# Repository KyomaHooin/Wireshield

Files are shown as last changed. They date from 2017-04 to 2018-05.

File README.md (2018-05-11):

DESCRIPTION

Server Rack Waste Heat Monitoring.

FILE
<pre>
                 avr/ - Atmega code.
               photo/ - Photo documentation.
               kicad/ - KiCAD schematic and PCB.
            openscad/ - OpenSCAD case model.
           raspberry/ - RPi code.
wireshield_schema.pdf - Shield schematic.
</pre>
SOURCE

https://github.com/KyomaHooin/Wireshield

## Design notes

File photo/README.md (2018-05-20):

DESCRIPTION

Photo documentation for Wireshield.

FILE
<pre>
IMG_20170406_092021.jpg - LED blinking.
IMG_20170406_093931.jpg - Activity LED added.
IMG_20170407_105513.jpg - Raspberry connection.
IMG_20170412_122922.jpg - Temp sensor added.
IMG_20170419_115917.jpg - TFT display test.
IMG_20170502_114444.jpg - Temp sensor connected via Cat 5e.
IMG_20170718_132216.jpg - PCB.
IMG_20170807_113755.jpg - Testing PCB.
IMG_20170830_094421.jpg - Test revision 2.0.
IMG_20170830_094432.jpg - TFT display test.
IMG_20180214_163721.jpg - 3D print case prototype.
IMG_20180219_162749.jpg - Front view of Wireshield (with wrong screwed screw)
IMG_20180219_162757.jpg - Side view of Wireshield (without button)
IMG_20180220_111011.jpg - Side view of Wireshield 
IMG_20180220_111004.jpg - Front view of Wireshield
IMG_20180412_110601.jpg - Final box connector side.
IMG_20180412_110608.jpg - Final box.
</pre>

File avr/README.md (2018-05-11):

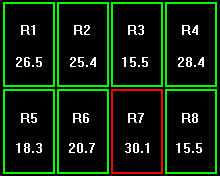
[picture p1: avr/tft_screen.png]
TFT


DESCRIPTION

OneWire AVR shield Atmega328 code.

FILE

<pre>
     rpishield.ino - Main  Program.
    tft_screen.png - Display screenshot.
       OneWire.zip - Dallas Onewire bus library by Paul Stoffregen (c) 2017.
      LowPower.zip - Low power library by Lim Phang Moh.
TFT_22_ILI9225.zip - ILI9225 TFT HW SPI driver by Johan Cronje Nkawu (c) 2017.
</pre>

SOURCE

https://github.com/KyomaHooin/Wireshield

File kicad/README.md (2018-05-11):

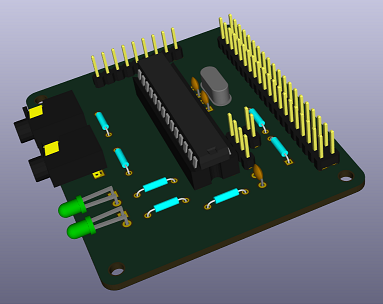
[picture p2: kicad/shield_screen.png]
Shield


DESCRIPTION

Raspberry RPi2 OneWire AVR shield PCB.

FILE
<pre>
                3d/ - 3D models by Walter Lain (c) 2015.
  footprint.pretty/ - Custom footprints.
rpishield.kicad_pcb - PCB layout.
      rpishield.pro - Project file.
      rpishield.lib - Project library.
      rpishield.sch - Custom schematic.
      rpishield.net - Trace list.
  shield_screen.png - Board screenshot.
</pre>
SOURCE

https://github.com/KyomaHooin/Wireshield

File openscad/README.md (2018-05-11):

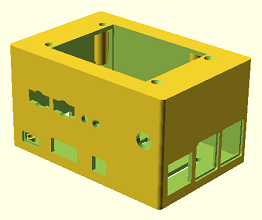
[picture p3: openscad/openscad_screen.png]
Openscad


DESCRIPTION

Raspberry RPi2 AVR shield & TFT display case.

FILE
<pre>
            schema/ - Dimension schematics.

rpishield_bottom.stl - Bottom STL file.
rpishield_spacer.stl - Spacer STL file.
   rpishield_top.stl - Top STL file.
      rpishield.scad - Complete code.
         shield.scad - Shield code.
            rpi.scad - RPi code.
            tft.scad - TFT display code.
             fc.scad - Helper functions.
 openscad_screen.png - 3D model screenshot.
</pre>
SOURCE

https://github.com/KyomaHooin/Wireshield

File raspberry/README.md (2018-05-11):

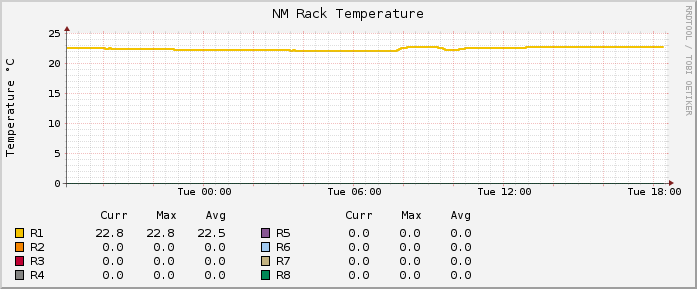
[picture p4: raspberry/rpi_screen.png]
RPI


DESCRIPTION

RPi2 AVR shield server configuration.

INSTALL
<pre>
apt-get install apache2 python-serial python-rrdtool watchdog

raspi-config > Interfacing Options > Serial > logging [no] > device [yes]

systemctl disable serial-getty@ttyAMA0.service

/etc/rc.local:

/root/avr/rpi-avr.py &
/root/avr/rstpwr.py &
/root/firewall &

/etc/network/interfaces:

auto eth0
iface eth0 inet static
	address 10.10.19.222
	netmask 255.255.0.0
	gateway 10.10.10.43
	dns-nameservers 10.10.9.26 10.10.9.27

/etc/watchdog.conf:

watchdog-device = /dev/watchdog
watchdog-timeout = 15

/etc/ntp.conf:

server tik.cesnet.cz
server tak.cesnet.cz

/etc/apache2/sites-enabled/000-default.conf:

ServerName xxx.xx.cz

DocumentRoot /var/www/rpishield

&lt;Directory /var/www/rpishield/plot&gt;
Options -Indexes -Multiviews
Order Allow,Deny
Allow from all
&lt;/Directory&gt;
</pre>
FILE
<pre>
     frontend/ - HTML frontend.

    rpi-avr.py - AVR data processing.
     rstpwr.py - Reset/halt detection.
   database.py - Create RRD database.
      firewall - Firewall script.
rpi_screen.png - Plot output.
</pre>
SOURCE

https://github.com/KyomaHooin/Wireshield

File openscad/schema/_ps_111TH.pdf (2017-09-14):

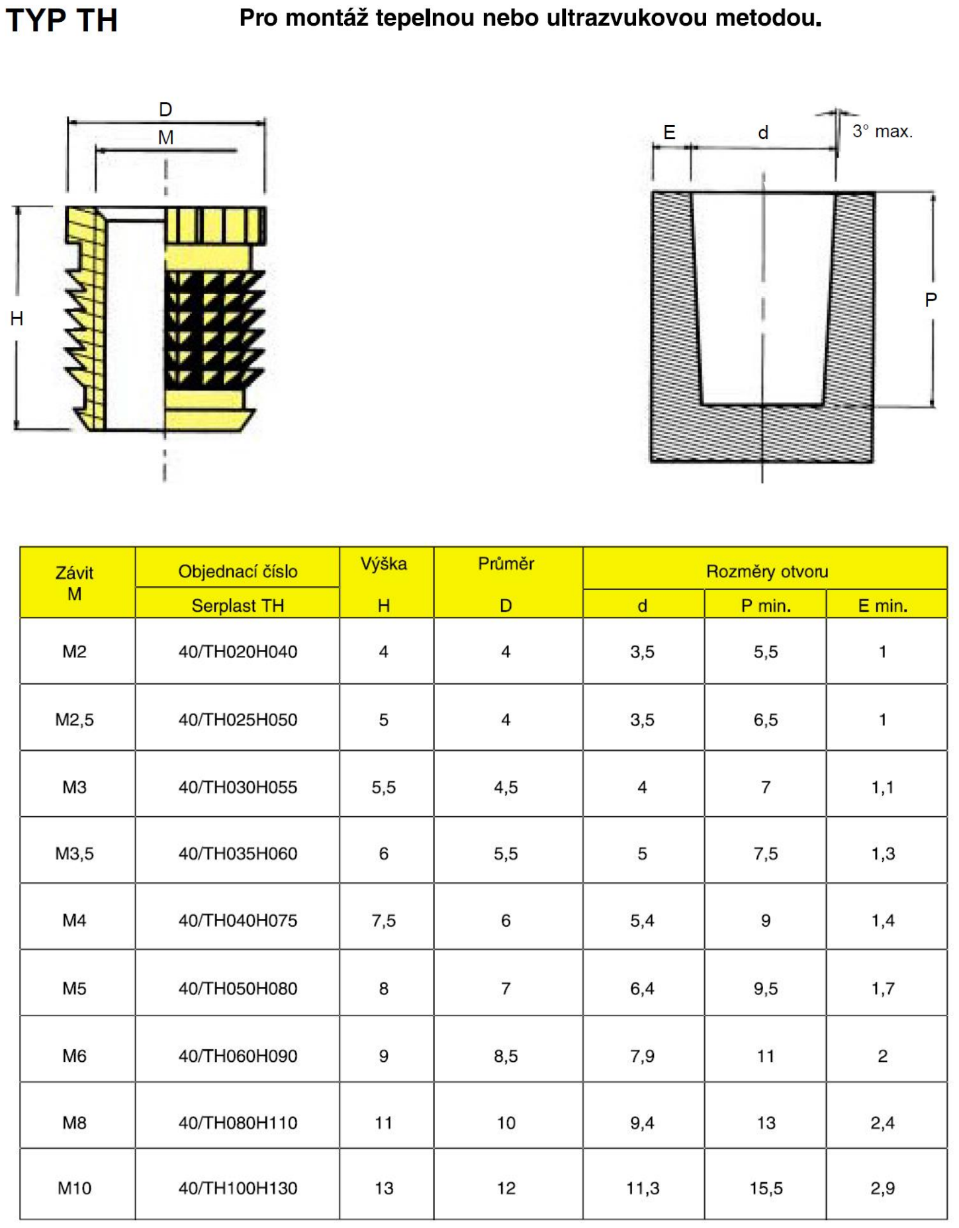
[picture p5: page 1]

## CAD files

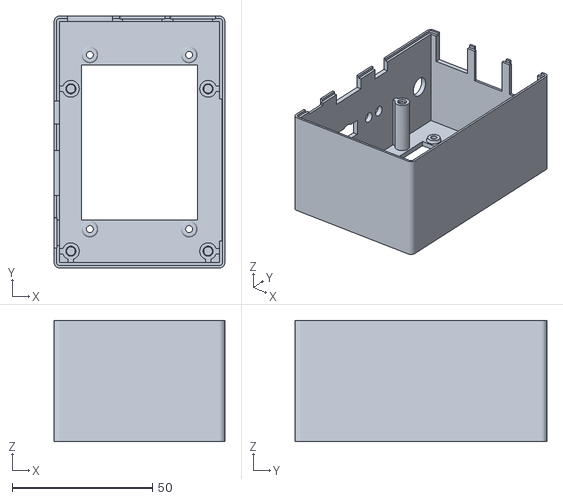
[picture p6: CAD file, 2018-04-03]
openscad/rpishield_top.stl
61.0 x 90.0 x 43.3

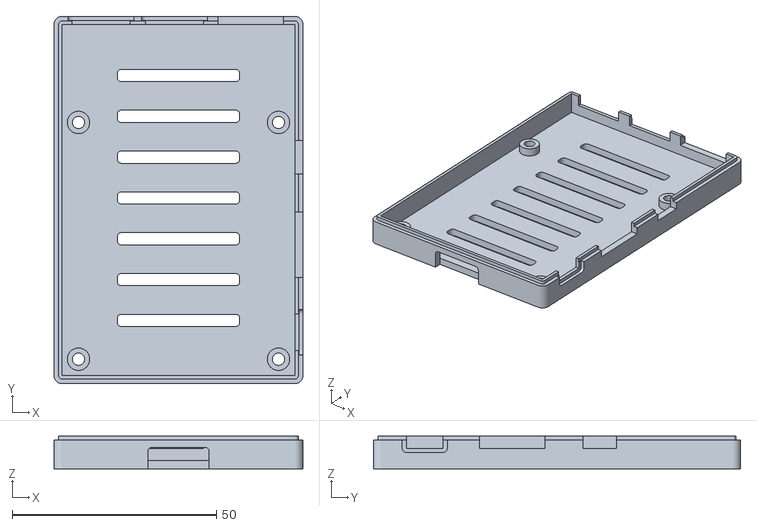
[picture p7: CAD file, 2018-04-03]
openscad/rpishield_bottom.stl
61.0 x 90.0 x 8.01

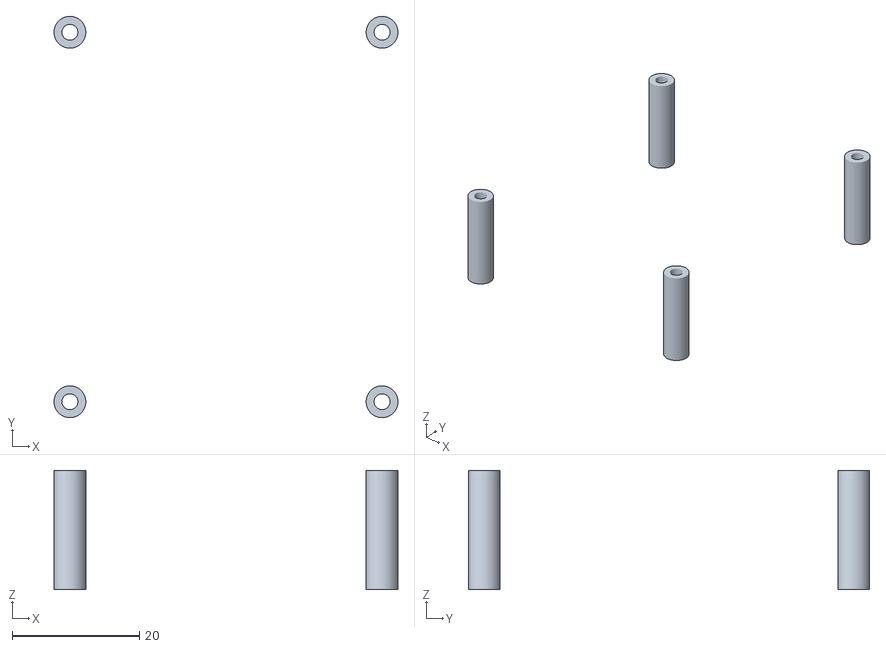
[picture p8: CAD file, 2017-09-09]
openscad/rpishield_spacer.stl
54.0 x 63.0 x 18.7

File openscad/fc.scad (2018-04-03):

//
// RPi Shield - functions
//

module rounded_rect(x, y, z, radius) {
    linear_extrude(height=z)
        minkowski() {
            square([x,y]);
            circle(r = radius);
        }
}

module bottom_hole() {
    translate([piHoleOffset, piHoleOffset,-1]) cylinder(h=bottomThick+2, d=3);
    translate([piX-piHoleOffset, piHoleOffset,-1]) cylinder(h=bottomThick+2, d=3);
    translate([piHoleOffset, shieldY-piHoleOffset,-1]) cylinder(h=bottomThick+2, d=3);
    translate([piX-piHoleOffset, shieldY-piHoleOffset,-1]) cylinder(h=bottomThick+2, d=3);
}

module bottom_mount(offsetX,offsetY,Thick) {
    difference() {
        translate([offsetX, offsetY, Thick]) cylinder(h=bottomMountHeight, d=bottomMountDia);
        translate([offsetX, offsetY, Thick-1]) cylinder(h=bottomMountHeight+2, d=3);
    }
}

module spacer(offsetX,offsetY) {
    difference() {
        translate([offsetX, offsetY,0]) cylinder(h=spacerHeight, d=5);
        translate([offsetX, offsetY,-1]) cylinder(h=spacerHeight+2, d=2.5);
    }
}

module top_mount(offsetX,offsetY,Thick) {
    difference() {
        translate([offsetX, offsetY, Thick]) cylinder(h=spacerHeight+displayThick+topDisplayMountHeight, d=topMountDia);
        translate([offsetX, offsetY, Thick-1]) cylinder(h=spacerHeight+displayThick+topDisplayMountHeight, d=topMountHoleDia);
        translate([offsetX, offsetY, Thick-1]) cylinder(h=2, d=3.6);
    }
}

module top_mount_low(offsetX,offsetY,Thick) {
    difference() {
        translate([offsetX, offsetY, Thick]) cylinder(h=spacerHeight+displayThick+topDisplayMountHeight-0.5, d=topMountDia);
        translate([offsetX, offsetY, Thick-1]) cylinder(h=spacerHeight+displayThick+topDisplayMountHeight-0.5, d=topMountHoleDia);
        translate([offsetX, offsetY, Thick-1]) cylinder(h=2, d=3.6);
    }
}

module top_display_hole() {
    translate([displayHoleOffsetX,displayHoleOffsetY,topHeight-topThick-1])
        cylinder(h=topThick+2, d=2.5);
    translate([displayHoleOffsetXX,displayHoleOffsetY,topHeight-topThick-1])
        cylinder(h=topThick+2, d=2.5);
    translate([displayHoleOffsetX,displayHoleOffsetYY,topHeight-topThick-1])
        cylinder(h=topThick+2, d=2.5);
    translate([displayHoleOffsetXX,displayHoleOffsetYY,topHeight-topThick-1])
        cylinder(h=topThick+2, d=2.5);
}

module top_display_mount(offsetX,offsetY,Thick) {
    difference() {
        translate([offsetX, offsetY, Thick]) cylinder(h=topDisplayMountHeight, r1=topDisplayMountDia/2, r2=topDisplayMountDia/2+0.5);
        translate([offsetX, offsetY, Thick-1]) cylinder(h=topDisplayMountHeight+2, d=topDisplayMountHoleDia);
    }
}

module top_sink() { cylinder(h=1.5, r1=1.25, r2=2.35); }

module usb_lip() {
    translate([1, bottomThick/2,0])
        rotate([90,0,0])
            rounded_rect(usbWidth, usbHeight, bottomThick/2, 1);
}

module micro_lip() {
    translate([bottomThick/2, 1, 0])
        rotate([0,270,0])
            rounded_rect(microHeight+1, microLength, bottomThick/2, 1);
}

module shield_lip() {
    translate([bottomThick/2, 1, 0])
        rotate([0,270,0])
            rounded_rect(shieldJackHeight, 2*shieldJackWidth+2.37, bottomThick/2, 1);
}

module sd_lip() {
    rotate([270,0,0])
        rounded_rect(cardWidth, bottomThick+bottomMountHeight, bottomThick, 1);
}

module lip_lock_bottom() {
    difference() {
        rounded_rect(bottomX+1, bottomY+1, 1, bottomThick);
        rounded_rect(bottomX+1, bottomY+1, 1, bottomThick/2-0.125);
    }
}

module lip_lock_top() {
    rounded_rect(bottomX+1, bottomY+1, 1, bottomThick/2+0.125);// bug
}

module harden() {
    cube([piHoleOffset-topMountDia/2+(topMountDia-topMountHoleDia)/2, topThick,
        spacerHeight+displayThick+topDisplayMountHeight]);
}

module harden_low() {
    cube([piHoleOffset-topMountDia/2+(topMountDia-topMountHoleDia)/2, topThick,
        spacerHeight+displayThick+topDisplayMountHeight-0.5]);
}

module button() {
    color("silver")
    rotate([0,90,0]) cylinder(h=15,d=8);
    translate([19,0,0])
        color("red")
        rotate([0,90,0]) cylinder(h=4,d=6); 
    translate([15,0,0])
        color("silver")
        rotate([0,90,0]) cylinder(h=4,d=4);
}

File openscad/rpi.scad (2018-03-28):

//
//RPI Shiled - RPi
//

$fn=50;

piX=56;// RPi.png
piY=85;// RPi.png
piThick=1.27;
piHoleDia=2.75;// RPi.png
piShieldLength=65;// RPi.png
piHoleOffset=3.5;// RPi.png

usbWidth=13.16+1;
usbLength=17.05;
usbHeight=17.03-piThick+1;
usb1X=piX-29-usbWidth/2;// RPi.png
usb2X=piX-47-usbWidth/2;// RPi.png
usbOverHang=1.84;

ethWidth=15.06+1;
ethLength=21.26;
ethHeight=15.00-piThick+1;
ethX=piX-10.25-(ethWidth/2);// RPi.png
ethOverHang=2.32;

avWidth=7.20+1;
avLength=15;
avHeight=7.47-piThick+1;
avOverHang=2.44;
avY=53.5-avWidth/2;// RPi.png

hdmiWidth=11.47;
hdmiLength=15.04+1;
hdmiHeight=7.86-piThick+1;
hdmiOverHang=1.59;
hdmiY=32-(hdmiLength/2);// RPi.png

microWidth=5.59;
microLength=8.04+1;
microHeight=4.22-piThick;
microOverHang=1.9;
microY=10.6-(microLength/2);// RPi.png

gpioWidth=2.54*2;// pls.jpg
gpioLength=20*2.54;// pls.jpg
gpioHeight=6.10+2.5;// pls.jpg
gpioX=1.05;// ?
gpioY=piHoleOffset+29-gpioLength/2;// RPi.png

cardWidth=13.04;
cardLength=17.18;
cardHeight=1.0;
cardOverHang=2.63;
cardX=piX/2-cardWidth/2;

module pi_hole() {
    cylinder(h=piThick+2, d=piHoleDia);
}

module rpi(edgeCut=0) {
    color("seagreen")
    difference() {
        cube([piX, piY, piThick]);
        translate([piHoleOffset, piHoleOffset, -1]) pi_hole();
        translate([piX-piHoleOffset, piHoleOffset, -1]) pi_hole();
        translate([piHoleOffset, piShieldLength-piHoleOffset, -1]) pi_hole();
        translate([piX-piHoleOffset, piShieldLength-piHoleOffset, -1]) pi_hole();
    }
    color("Silver") {
        // USB
        translate([usb1X, piY-usbLength+usbOverHang+edgeCut, piThick-0.5])
            cube([usbWidth, usbLength, usbHeight]);
        translate([usb2X, piY-usbLength+usbOverHang+edgeCut, piThick-0.5])
            cube([usbWidth, usbLength, usbHeight]);
        // ETH
        translate([ethX, piY-ethLength+ethOverHang+edgeCut, piThick-0.5])
            cube([ethWidth, ethLength, ethHeight]);
        // HDMI Plug
        translate([piX-hdmiWidth+hdmiOverHang+edgeCut, hdmiY-0.5, piThick-0.5])
            cube([hdmiWidth, hdmiLength, hdmiHeight]);
        // AV
        translate([piX-avLength+avOverHang+edgeCut, avY-0.5, piThick-0.5])
            cube([avLength, avWidth, avHeight]);
        // microUSB
        translate([piX-microWidth+microOverHang+edgeCut, microY-0.5, piThick-0.5])
            cube([microWidth, microLength, microHeight+1]);
        // microSD
        translate([cardX, -cardOverHang-edgeCut, -cardHeight])
            cube([cardWidth, cardLength,cardHeight]);
    }
    // GPIO Headers
    color("black") {
        translate([gpioX, gpioY, piThick])
            cube([gpioWidth, gpioLength, gpioHeight]);
    }
}

//rpi();

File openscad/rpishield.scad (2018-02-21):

//
// RPi Wireshield Case 
//

include <shield.scad>;
include <tft.scad>;
include <rpi.scad>;
include <fc.scad>;

drawCaseTop=0;
drawCaseBottom=0;
drawSpacer=0;
drawAll=1;

$fn=50;

//------------------------------

//SPACER

spacerHeight=18.7;

module spacer_mount() {
    spacer(piHoleOffset, piHoleOffset);
    spacer(shieldX-piHoleOffset, piHoleOffset);
    spacer(piHoleOffset, shieldY-piHoleOffset);
    spacer(shieldX-piHoleOffset, shieldY-piHoleOffset);
}

//CASE BOTTOM

bottomThick=2;
bottomX=56;
bottomY=85;
bottomMountHeight=2.26;
bottomMountDia=5.5;
bottomHeight=bottomThick+bottomMountHeight+piThick+microHeight/2;

module case_bottom() {
    difference() {
        translate([-0.5,-0.5,0]) rounded_rect(bottomX+1, bottomY+1, bottomHeight+1, bottomThick);// BASE
        translate([-0.5,-0.5,bottomThick]) cube([bottomX+1, bottomY+1, bottomHeight]); // FILLER
        translate([0,0,bottomThick+bottomMountHeight]) rpi(edgeCut=3);// RPI
        bottom_hole();// BOTTOM HOLE
        for (vspace=[1:7])// VENT
            translate([piX/4, 10*vspace+2.5, -1]) rounded_rect(bottomX/2, 1, bottomThick+2, 1);
        translate([cardX, -bottomThick-0.5, bottomThick+bottomMountHeight]) sd_lip();// SD LIP
        translate([usb2X-1,bottomY+bottomThick/2+0.5,bottomThick+bottomMountHeight+piThick-0.5]) usb_lip();// USB LIP
        translate([usb1X-1,bottomY+bottomThick/2+0.5,bottomThick+bottomMountHeight+piThick-0.5]) usb_lip();
        translate([bottomX+bottomThick/2+0.5,microY-1-0.5,bottomThick+bottomMountHeight+piThick-0.5])// MICRO LIP
            micro_lip();
        translate([-0.5,-0.5,bottomHeight]) lip_lock_bottom();// LIPLOCK
    }
    bottom_mount(piHoleOffset, piHoleOffset, bottomThick);// BOTTOM MOUNT
    bottom_mount(piX-piHoleOffset,piHoleOffset, bottomThick);
    bottom_mount(piHoleOffset, shieldY-piHoleOffset, bottomThick);
    bottom_mount(piX-piHoleOffset, shieldY-piHoleOffset, bottomThick);
}

//CASE TOP

topThick=2;
topX=56;
topY=85;
topDisplayMountHeight=1.26;
topDisplayMountHoleDia=2.5;
topDisplayMountDia=5;
topMountHoleDia=3.1;
topMountDia=6;
topHeight=spacerHeight-microHeight/2+shieldThick+spacerHeight+displayThick+topDisplayMountHeight+topThick;

displayHoleOffsetX=(piX-displayX)/2+displayHoleX;
displayHoleOffsetY=(piY-displayY)/2+displayHoleY;
displayHoleOffsetXX=(piX-displayX)/2+displayX-displayHoleX;
displayHoleOffsetYY=(piY-displayY)/2+displayY-displayHoleY;

module case_top() {
    difference() {
        translate([-0.5,-0.5,-1]) rounded_rect(topX+1, topY+1, topHeight+1, topThick);// BASE
        translate([-0.5,-0.5,-topThick]) cube([topX+1, topY+1, topHeight]);// FILLER
        translate([0,0,-microHeight/2-piThick-1]) rpi(edgeCut=3);// RPI
        translate([0,0,spacerHeight-microHeight/2]) shield(shieldEdgeCut=5);// SHILED
        translate([(piX-displayX)/2+0.5, (piY-displayY)/2+5.82, 0])// SCREEN
            cube([displayX-1, screenLength, topHeight+1]);
        top_display_hole();// SCREEN HOLE
        translate([displayHoleOffsetX,displayHoleOffsetY,topHeight-1.5]) top_sink();// SCREEN HOLE SINK
        translate([displayHoleOffsetXX,displayHoleOffsetY,topHeight-1.5]) top_sink();
        translate([displayHoleOffsetX,displayHoleOffsetYY,topHeight-1.5]) top_sink();
        translate([displayHoleOffsetXX,displayHoleOffsetYY,topHeight-1.5]) top_sink();
        translate([-topThick/2-0.5,shieldGPIOY,0])// IDC LIP
            cube([topThick/2,shieldGPIOLength,topHeight-topThick]);
        translate([usb2X-1, topY+bottomThick/2+0.5, -microHeight/2-0.5-1]) usb_lip();// USB LIP
        translate([usb1X-1, topY+bottomThick/2+0.5, -microHeight/2-0.5-1]) usb_lip();
        translate([bottomX+bottomThick/2+0.5, microY-1-0.5, -microHeight/2-0.5-1]) micro_lip();// MICRO LIP
        translate([-0.5,-0.5,-1]) lip_lock_top();//LIP LOCK
        translate([topX-10,topY-7,spacerHeight-microHeight/2+shieldThick+4-1.5]) button();// PWR/RST 4 = dia/2        
    }
    //TOP MOUNT
    top_mount(piHoleOffset, piHoleOffset, spacerHeight-microHeight/2+shieldThick);
    top_mount_low(piX-piHoleOffset,piHoleOffset, spacerHeight-microHeight/2+shieldThick+0.5);
    top_mount(piHoleOffset, shieldY-piHoleOffset, spacerHeight-microHeight/2+shieldThick);
    top_mount_low(piX-piHoleOffset, shieldY-piHoleOffset, spacerHeight-microHeight/2+shieldThick+0.5);
    //DISPLAY MOUNT
    top_display_mount(displayHoleOffsetX,displayHoleOffsetY,topHeight-topThick-topDisplayMountHeight);
    top_display_mount(displayHoleOffsetXX,displayHoleOffsetY,topHeight-topThick-topDisplayMountHeight);
    top_display_mount(displayHoleOffsetX,displayHoleOffsetYY,topHeight-topThick-topDisplayMountHeight);
    top_display_mount(displayHoleOffsetXX,displayHoleOffsetYY,topHeight-topThick-topDisplayMountHeight);
    //HARDEN
    translate([-1, piHoleOffset-topThick/2, spacerHeight-microHeight/2+shieldThick]) harden();
    translate([piX-topThick/2, piHoleOffset-topThick/2, spacerHeight-microHeight/2+shieldThick+0.5]) harden_low();
    translate([-1, shieldY-piHoleOffset-topThick/2, spacerHeight-microHeight/2+shieldThick]) harden();
    translate([piX-topThick/2, shieldY-piHoleOffset-topThick/2, spacerHeight-microHeight/2+shieldThick+0.5]) harden_low();
    translate([piHoleOffset-topThick/2, -topThick/2, spacerHeight-microHeight/2+shieldThick]) harden();
    translate([piX-piHoleOffset-topThick/2, -topThick/2, spacerHeight-microHeight/2+shieldThick+0.5]) harden_low();
}

//------------------------------

if (drawCaseTop) {
    translate([topX+topThick+0.5, topThick+0.5, topHeight])
        rotate([0,180,0]) case_top();
}

if (drawCaseBottom) {
    translate([topThick+0.5, topThick+0.5, 0]) case_bottom();
}

if(drawSpacer) { spacer_mount(); }

if (drawAll) {
    translate([0,0,0]) case_bottom();
    translate([0,0,bottomThick+bottomMountHeight]) rpi();
    translate([0,0,bottomThick+bottomMountHeight+piThick+1]) spacer_mount();
    translate([0,0,bottomThick+bottomMountHeight+piThick+spacerHeight+1]) shield();
    translate([topX-10,topY-7,bottomThick+bottomMountHeight+piThick+spacerHeight+shieldThick+4-1.5+1]) button();
    translate([(piX-displayX)/2, (piY-displayY)/2,
        bottomHeight+topHeight-topThick-topDisplayMountHeight-displayThick+1])
        display();
    translate([0,0,bottomHeight+1]) case_top();
}

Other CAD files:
openscad/shield.scad
openscad/tft.scad

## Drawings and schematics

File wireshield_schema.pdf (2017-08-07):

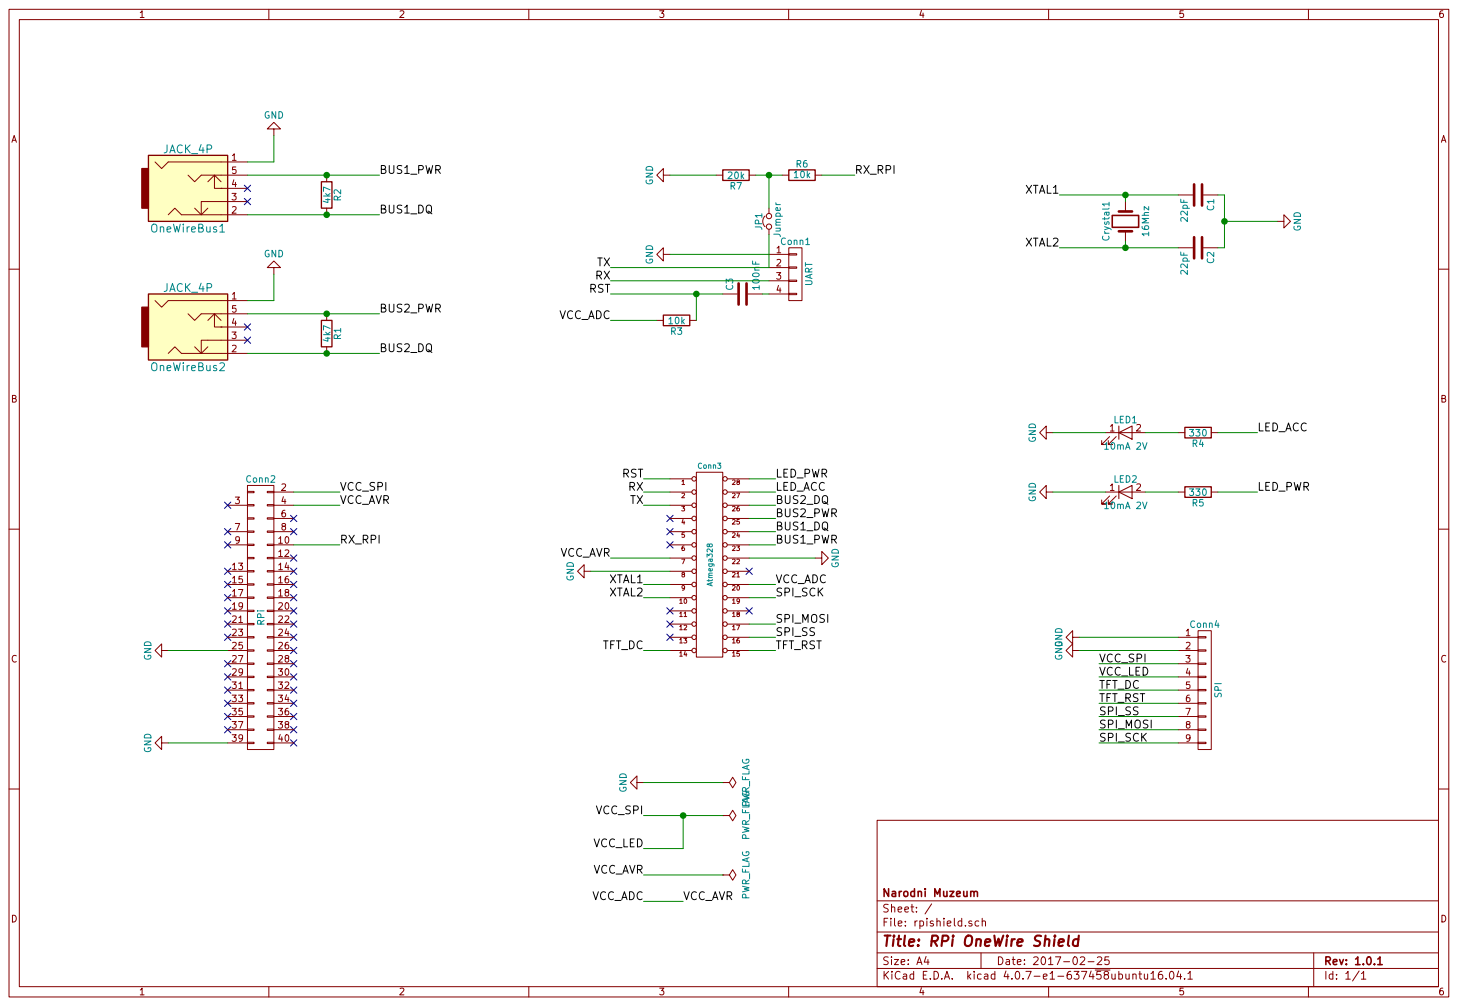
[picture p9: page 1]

Id: 1/1 Title: RPi OneWire Shield

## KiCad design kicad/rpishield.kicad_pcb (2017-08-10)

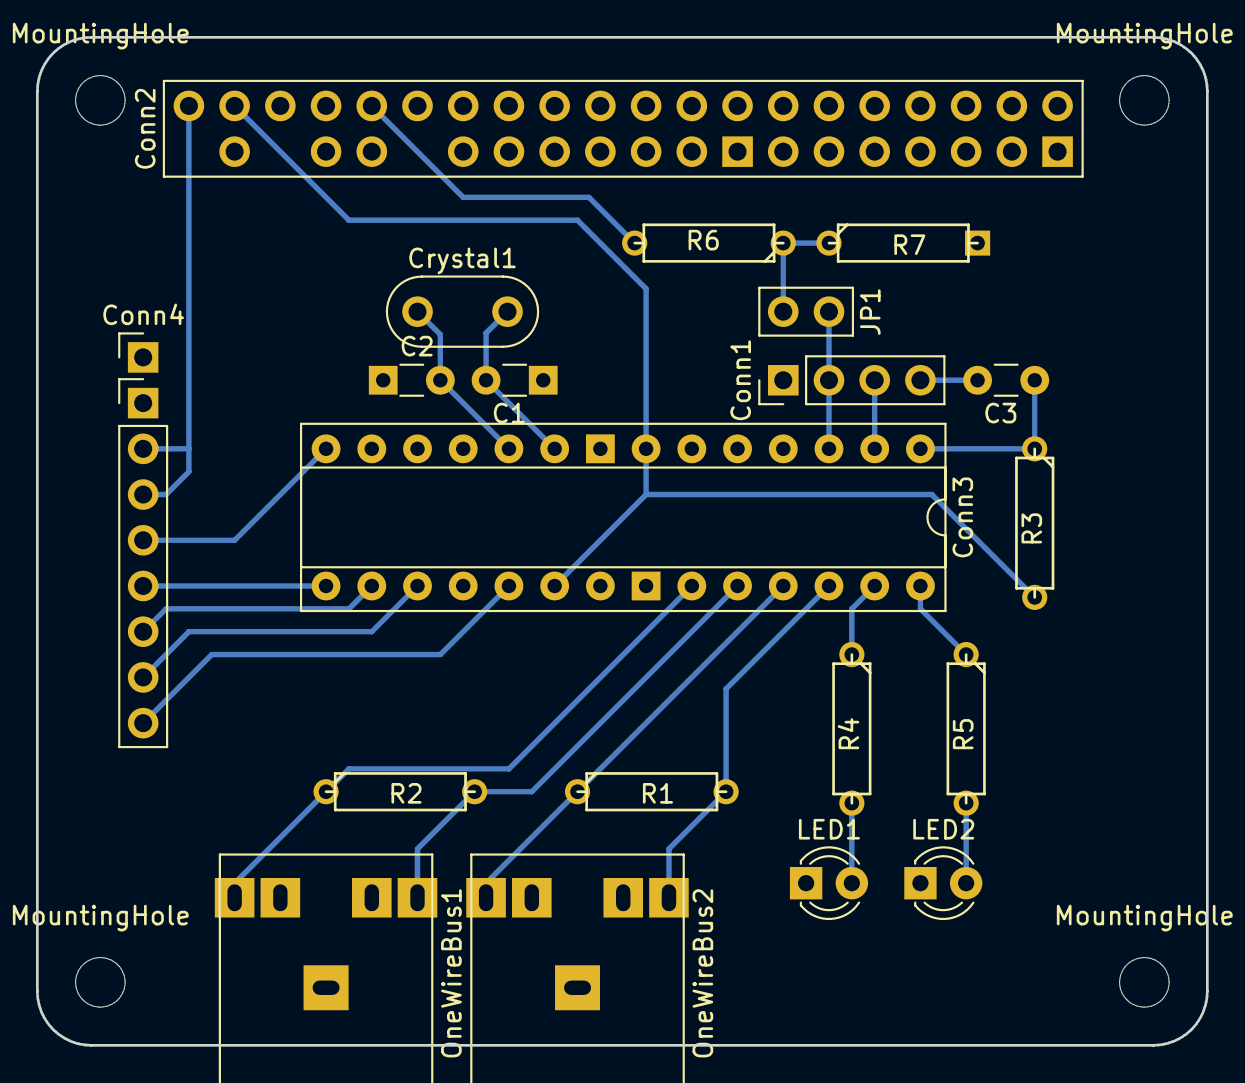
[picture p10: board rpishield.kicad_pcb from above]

Board: 2 copper layers, 65.0 x 56.0 mm, 24 parts (0 on the bottom side), 24 nets.

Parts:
C1, C2: 22pF; Custom_Disc_D3.0mm_W1.6mm_P3.175mm
C3: 100nF; Custom_Disc_D3.0mm_W1.6mm_P3.175mm_normal
Conn1: UART; Socket_Strip_Straight_1x04_Pitch2.54mm
Conn2: RPi; Custom_Header_2x20_Pitch2.54mm
Conn3: Atmega328; Custom_DIP-28_W7.62mm_Socket
Conn4: SPI; Custom_Pin_Header_Straight_1x09_Pitch2.54mm
Crystal1: 16Mhz; Resonator-2pin_w8.0mm_h3.5mm
JP1: Jumper; Custom_Pin_Header_Straight_1x02_Pitch2.54mm
LED1, LED2: 10mA 2V; LED_D3.0mm_FlatTop
MountingHole: MountingHole_2.75mm_M2.5; Custom_MountingHole_2.75mm_M2.5
MountingHole#2, MountingHole#3, MountingHole#4: MountingHole_2.75mm_M2.5; Custom_MountingHole_2.75mm_M2.5
OneWireBus1, OneWireBus2: JACK_4P; Custom_Barrel_Jack
R1, R2: 4k7; Custom_R3_normal
R3, R6: 10k; Custom_R3_normal
R4, R5: 330; Custom_R3_normal
R7: 20k; Custom_R3

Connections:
/BUS1_DQ: Conn3.24, OneWireBus1.2, R2.2
/BUS1_PWR: Conn3.23, OneWireBus1.5, R2.1
/BUS2_DQ: Conn3.26, OneWireBus2.2, R1.2
/BUS2_PWR: Conn3.25, OneWireBus2.5, R1.1
/LED_ACC: Conn3.27, R4.1
/LED_PWR: Conn3.28, R5.1
/RST: C3.1, Conn3.1, R3.1
/RX: Conn1.3, Conn3.2
/RX_RPI: Conn2.10, R6.2
/SPI_MOSI: Conn3.17, Conn4.8
/SPI_SCK: Conn3.19, Conn4.9
/SPI_SS: Conn3.16, Conn4.7
/TFT_DC: Conn3.14, Conn4.5
/TFT_RST: Conn3.15, Conn4.6
/TX: Conn1.2, Conn3.3, JP1.1
/VCC_ADC: Conn2.4, Conn3.7, Conn3.20, R3.2
/VCC_LED: Conn2.2, Conn4.3, Conn4.4
/XTAL1: C1.2, Conn3.9, Crystal1.2
/XTAL2: C2.2, Conn3.10, Crystal1.1
GND: C1.1, C2.1, Conn1.1, Conn2.25, Conn2.39, Conn3.8, Conn3.22, Conn4.1, Conn4.2, LED1.1, LED2.1, OneWireBus1.1, OneWireBus2.1, R7.2
unnamed: C3.2, Conn1.4
unnamed: JP1.2, R6.1, R7.1
unnamed: LED1.2, R4.2
unnamed: LED2.2, R5.2

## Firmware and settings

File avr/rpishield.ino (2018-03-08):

//
// RPi OneWire Shield 
//

#include<OneWire.h>
#include<LowPower.h>
#include<TFT_22_ILI9225.h>// 176x220

#define BUS1_PWR A0
#define BUS1_DQ  A1
#define BUS2_PWR A2
#define BUS2_DQ  A3
#define LED_ACC  A4
#define LED_PWR  A5
#define TFT_RS   8 // TFT D/C
#define TFT_RST  9 // TFT RST
#define TFT_CS   10// SPI SS
#define TFT_SDI  11// SPI MOSI
#define TFT_CLK  13// SPI SCK

//OneWire instance
OneWire Bus1(BUS1_DQ);
OneWire Bus2(BUS2_DQ);
//TFT HW SPI instance
TFT_22_ILI9225 tft(TFT_RST,TFT_RS,TFT_CS,0);

//VAR

int maxtemp = 30;// Maximum temperature.

byte sensor[8][8] = {
  0x28,0xff,0xaa,0xd9,0xb2,0x17,0x04,0x44,// Bus1[sensor 1-4]
  0x28,0xff,0x98,0x07,0xb2,0x17,0x04,0x57,
  0x28,0xff,0xa5,0x2b,0xb2,0x17,0x05,0x03,
  0x28,0xff,0x4c,0xd6,0xb1,0x17,0x04,0x7c,
  0x28,0xff,0x7b,0xb2,0xb1,0x17,0x04,0x37,// Bus2[sensor 5-8]
  0x28,0xff,0x8f,0x96,0xb1,0x17,0x04,0xf0,
  0x28,0xff,0x25,0xb1,0xb1,0x17,0x04,0x88,
  0x28,0xff,0x1b,0xb0,0x70,0x16,0x05,0x43
};

//SETUP

void setup() {
  //UART
  Serial.begin(9600);
  //OneWire
  pinMode(BUS1_PWR, OUTPUT);
  digitalWrite(BUS1_PWR, HIGH);
  pinMode(BUS2_PWR, OUTPUT);
  digitalWrite(BUS2_PWR, HIGH);
  //LED
  pinMode(LED_PWR, OUTPUT);
  digitalWrite(LED_PWR, HIGH);
  pinMode(LED_ACC, OUTPUT);
  digitalWrite(LED_ACC, LOW); 
  //TFT
  tft.begin();
  tft.setOrientation(1);
  tft.setFont(Terminal6x8);
  tft.clear();
}

//MAIN

void loop() {
  float temperature;
  char msg[6], payload[48] = {};
  for (int i = 0; i < 4; i++) {
    ds_temp_request(Bus1,sensor[i]);
    temperature = ds_get_temperature(Bus1,sensor[i]);
    if ( temperature <= 0 ) { temperature = 0; }
    sprintf(msg, "S%dT%03d", i, int(temperature * 10));
    strcat(payload,msg);
    tft_update(i,temperature);
  }
  for (int i = 4; i < 8; i++) {
    ds_temp_request(Bus2,sensor[i]);
    temperature = ds_get_temperature(Bus2,sensor[i]);
    if ( temperature <= 0 ) { temperature = 0; }
    sprintf(msg, "S%dT%03d", i, int(temperature * 10));
    strcat(payload,msg);
    tft_update(i,temperature);
  }
  Serial.println(payload);
  led_flash();
  for (int i = 0; i < 74; i++) {// 5min sleep
    LowPower.powerDown(SLEEP_4S, ADC_OFF, BOD_OFF);
  }
}

//FUNC

//Blink half a sec.
void led_flash() {
  digitalWrite(LED_ACC,HIGH);
  delay(100);
  digitalWrite(LED_ACC,LOW);
}

//Bus request temperature
void ds_temp_request(OneWire &ds, byte addr[8]) {
  ds.reset();
  ds.select(addr);
  ds.write(0x44);//"Convert T".
  delay(750); //12-Bit resolution delay.
}

//Bus calculate temperature.
float ds_get_temperature(OneWire &ds, byte addr[8]) {
  byte ds_data[2];
  ds.reset();
  ds.select(addr);
  ds.write(0xbe); //"Read Scratchpad".
  ds.read_bytes(ds_data,2); //LSB & MSB
  short raw = ds_data[1] << 8 | ds_data[0]; //2-Byte to 16 bit int
  return (float)raw / 16.0; //-> int to double precission float
}

//TFT background template 52x85 square 2px spacing
void tft_rectangle(int id, float val) {
  unsigned long color;
  (val > 0 && val < maxtemp) ? color = COLOR_GREEN : color = COLOR_RED;
  if(id < 4) {
     tft.drawRectangle(2 + 2*id + 52*id, 2, 54 + 2*id + 52*id, 87, color);
     tft.drawRectangle(2 + 2*id + 52*id + 1, 3, 54 + 2*id + 52*id - 1, 86, color);
  } else {
     tft.drawRectangle(2 + 2*(id-4) + 52*(id-4), 89, 54 + 2*(id-4) + 52*(id-4), 174 , color);
     tft.drawRectangle(2 + 2*(id-4) + 52*(id-4) + 1, 90, 54 + 2*(id-4) + 52*(id-4) - 1, 173 , color);
  }
}

//TFT draw value
void tft_update(int id, float val) {
  String offset;
  String sid = String("R") + String(id + 1);
  if (val >= 0 && val < 10) { offset = String(' '); }
  String tmp = offset + String(int(val)) + String(".") + String(int(val*10) % 10);
  if (id < 4) {
      tft.drawText(21 + 2*id + 52*id, 28, sid, COLOR_WHITE);
      tft.drawText(15 + 2*id + 52*id, 53, tmp, COLOR_WHITE);
  } else {
      tft.drawText(21 + 2*(id-4) + 52*(id-4), 115, sid, COLOR_WHITE);
      tft.drawText(15 + 2*(id-4) + 52*(id-4), 140, tmp, COLOR_WHITE);
  }
  tft_rectangle(id, val);
}

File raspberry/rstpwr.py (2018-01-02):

#!/usr/bin/python
#
# RPi GPIO 32 RST/PWR button
#

import time,sys,os

try:
	import RPi.GPIO as GPIO
except:
	print "Missing GPIO library."
	sys.exit(1)

GPIO.setmode(GPIO.BOARD)
GPIO.setup(32,GPIO.IN, pull_up_down=GPIO.PUD_UP)# pull-up

def rstpwr():
	counter = 0
	while 1:
		if not GPIO.input(32):# pressed = 0
			counter += 1
		else:
			if 6 > counter > 2:
				os.system('reboot')
				return
			elif counter >= 6:
				os.system('halt')
				return
			else: return
		time.sleep(1)

while 1:
	pressed = GPIO.wait_for_edge(32,GPIO.FALLING)
	if pressed: rstpwr()

GPIO.clenup()

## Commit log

2017-02-21 Kicad schema.
    [rpishield.kicad_pcb, rpishield.sch]
2017-02-21 Fix conn label.
    [rpishield.sch]
2017-02-21 Schema update.
    [rpishield.sch]
2017-02-22 Kicad schema, PCB update.
    [rpishield.kicad_pcb, rpishield.sch]
2017-02-23 PCB schematic update.
    [rpishield.kicad_pcb]
2017-02-23 3D models.
    [rpishield.kicad_pcb]
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2017-02-24 Round corner, via, gnd pour.
    [rpishield.kicad_pcb, rpishield.sch]
2017-02-25 20x2 pin strip.
    [rpishield.kicad_pcb, rpishield.sch]
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2017-02-25 Distance rule, custom header.
    [rpishield.kicad_pcb, rpishield.sch]
2017-02-25 Ground fill, RPi pinhole, schema lib, cleanup.
    [rpishield.kicad_pcb, rpishield.sch]
2017-02-26 Obsolate models, RX/RT fix.
    [rpishield.kicad_pcb, rpishield.sch]
2017-02-26 Ground pad, track cleanup.
    [rpishield.kicad_pcb, rpishield.sch]
2017-02-26 Better Jack track.
    [rpishield.kicad_pcb]
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2017-03-16 SPI, LED, R, C footprint, path update.
    [rpishield.kicad_pcb]
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2017-03-20 Scad init.
    [rpibox_bottom.scad]
2017-03-25 SCAD TODO.
    [rpibox_bottom.scad]
2017-03-30 TFT SPI, schema update.
    [rpishield.kicad_pcb, rpishield.sch]
2017-04-04 Case code update.
    [rpibox_bottom.scad, rpishield.scad]
2017-04-04 Top, bottom update.
    [rpishield.scad]
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2017-04-05 Mount hole/buffer.
    [rpishield.scad]
2017-04-06 Pi,shield components.
    [rpishield.scad]
2017-04-06 SPI, spacer.
    [rpishield.scad]
2017-04-07 Fix xonxoff flow control.
    [rpi-avr.py]
2017-04-07 Top case, raw shiled component.
    [rpishield.scad]
2017-04-09 AVR delay, var fix.
    [rpi-avr.py, rpishield.ino]
2017-04-12 Sensor var, payload fix.
    [rpishield.ino]
2017-04-12 Temperature error.
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2017-04-13 Lower temperature fix.
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2017-04-17 Stereo jack update.
    [rpishield.kicad_pcb, rpishield.sch]
2017-04-17 SPI foot.
    [rpishield.kicad_pcb]
2017-04-20 Mounthole,Jack,Crystal PCB fix.
    [rpishield.kicad_pcb]
2017-04-20 Board,LED,AVR spacing.
    [rpishield.kicad_pcb]
2017-04-20 Hole fix.
    [rpishield.kicad_pcb]
2017-04-22 Crystal layout.
    [rpishield.kicad_pcb]
2017-04-22 Jack update.
    [rpishield.kicad_pcb]
2017-04-22 Jack 3D model fix.
    [rpishield.kicad_pcb]
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2017-05-02 Idle/sleep, acct. lex fix.
    [rpishield.ino]
2017-07-20 RST path.
    [rpishield.kicad_pcb]
2017-07-20 Jack schema, RST bug.
    [rpishield.sch]
2017-07-20 Rule check.
    [rpishield.kicad_pcb]
2017-08-07 Header, MOSI, RX, Jumper.
    [rpishield.sch]
2017-08-07 SPI VCC, Jumper, MOSI track.
    [rpishield.kicad_pcb]
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2017-08-07 0.3mm track.
    [rpishield.kicad_pcb]
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2017-08-10 R/C footprint update.
    [rpishield.sch]
2017-08-10 R/C footprint pad + 0.625 mm.
    [rpishield.kicad_pcb]
2017-08-10 Layout tune, 3D offsets.
    [rpishield.kicad_pcb]
2017-08-10 LED R offset fix.
    [rpishield.kicad_pcb]
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2017-08-18 TFT code.
    [tft.scad]
2017-08-18 Shield code.
    [shield.scad]
2017-08-18 RPi code.
    [rpi.scad]
2017-08-18 SPI, typo.
    [tft.scad]
2017-08-18 New base rewrite backup.
    [new.scad]
2017-08-19 Support funtions.
    [func.scad]
2017-08-19 Func. name.
    [shield.scad]
2017-08-19 Func. name, minor fixes.
    [rpi.scad]
2017-08-19 Rewritten code.
    [rpishield.scad]
2017-08-21 Top/bottom height, liplock, vent.
    [rpishield.scad]
2017-08-21 LED cylinder.
    [rpishield.scad, shield.scad]
2017-08-22 Micro SD.
    [rpi.scad]
2017-08-22 IDC cable, MicroSD card, Vent loop.
    [rpishield.scad]
2017-08-23 Top TFT hole.
    [rpishield.scad]
2017-08-23 Display mount.
    [func.scad, rpishield.scad]
2017-08-23 Fix top display mount.
    [rpishield.scad]
2017-08-24 Top display mount fix.
    [rpishield.scad]
2017-08-26 Display mount sink.
    [func.scad, rpishield.scad]
2017-08-27 Case mount hole.
    [func.scad, rpishield.scad]
2017-08-30 Numeric update.
    [func.scad, rpi.scad, rpishield.scad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]
2017-08-31 Minor fixes.
    [rpishield.scad, shield.scad, tft.scad]
2017-09-04 Case rewrite.
    [func.scad, rpishield.scad, tft.scad]
2017-09-04 Dimensions update.
    [rpi.scad, rpishield.scad, shield.scad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]
2017-09-07 Numeric update, code rewrite.
    [fc.scad, func.scad, rpishield.scad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]
2017-09-07 RPi lip, SD cut, cleanup.
    [fc.scad, rpishield.scad]
2017-09-07 Lip tune, grammar.
    [fc.scad, rpishield.scad, shield.scad]
2017-09-07 Thickness tune.
    [fc.scad, rpishield.scad]
2017-09-08 Lock, harden, fixes.
    [fc.scad, rpishield.scad]
2017-09-08 Top / mount height fix.
    [fc.scad, rpishield.scad]
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2017-09-09 Rounded PCB.
    [shield.scad]
2017-09-09 Lip-lock fix.
    [fc.scad, rpishield.scad]
2017-09-09 Show spacer, alignment.
    [rpishield.scad]
2017-09-09 STL output.
    [rpishield_bottom.stl, rpishield_spacer.stl, rpishield_top.stl]
2017-09-09 Syntax cleanup.
    [fc.scad, rpi.scad, rpishield.scad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]
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2017-09-10 Display screw update, display mount harden.
    [fc.scad, rpishield.scad, rpishield_top.stl]
2017-09-11 USB,DHMI,IDC,LED,screen numeric update.
    [fc.scad, rpi.scad, rpishield.scad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]
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2017-10-26 Button model.
    [fc.scad]
2017-10-26 Pwr/rst button.
    [rpishield.scad]
2017-10-26 Button update.
    [rpishield_top.stl]
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2018-01-02 Fix too short press.
    [rstpwr.py]
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2018-02-16 MicroUsb,HDMI width/length mismatch fix.
    [rpi.scad]
2018-02-16 TFT screen width/length fix.
    [rpishield.scad, tft.scad]
2018-02-16 Button dia +1.
    [fc.scad, shield.scad]
2018-02-16 LED +1mm dia.
    [shield.scad]
2018-02-16 Button +1mm dia + height.
    [fc.scad, rpishield.scad]
2018-02-16 LED +0.5mm Dia, JACK +1mm Width, JACK +8mm ring.
    [shield.scad]
2018-02-17 Button 00.5mm offset.
    [rpishield.scad]
2018-02-17 All compoment +1mm width/height +0.5mm offset.
    [rpi.scad]
2018-02-17 All +1mm width/length/dia +0.5mm offset.
    [shield.scad]
2018-02-18 Lip-lock fixes.
    [fc.scad, rpishield.scad]
2018-02-18 Shiled front spacer/harden -0.5mm.
    [fc.scad, rpishield.scad]
2018-02-18 Box width/length +0.5mm.
    [fc.scad, rpishield.scad]
2018-02-21 TFT 0.5mm top/bottom.
    [rpishield.scad, tft.scad]
2018-02-21 Bottom mount/hole +0.5mm dia.
    [fc.scad, rpishield.scad]
2018-02-21 Button position tune.
    [rpishield.scad]
2018-02-21 Brass insert mount hole.
    [fc.scad]
2018-02-21 USB lip harden.
    [fc.scad, rpishield.scad]
2018-02-21 Top +1mm height.
    [rpishield.scad]
2018-02-21 STL update.
    [rpishield_bottom.stl, rpishield_top.stl]
2018-02-21 Perm fix.
    [rpishield_bottom.stl, rpishield_top.stl]
2018-02-21 STL update jack.
    [rpishield_top.stl]
2018-02-21 Minor offset fix.
    [rpishield.scad]
2018-02-21 Jack height fix.
    [shield.scad]
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2018-03-28 Fix microHeight bug.
    [fc.scad, rpi.scad]
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2018-04-03 Jack possition fix.
    [shield.scad]
2018-04-03 Lip lock fix.
    [fc.scad]
2018-04-03 Top mount fix.
    [fc.scad]
2018-04-14 Sensor error comment.
